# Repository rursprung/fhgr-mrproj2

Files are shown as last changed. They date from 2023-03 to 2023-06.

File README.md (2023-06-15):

# Mobile Robotics Project 2




As part of the [FHGR BSc Mobile Robotics](https://fhgr.ch/mr) an autonomous vehicle with Lidar has been developed
as a group project by [Tim Barmettler](https://github.com/TimBarmettler4), [Joel Flepp](https://github.com/joel5399),
[Yan Gridling](https://github.com/Prince-Sigvald) and [Ralph Ursprung](https://github.com/rursprung) in the 4th
semester.

This repository contains both the code as well as [the PCB schematics](smt_PCB_files/README.md) and
[the 3D printing files](smt_3D_files/README.md) which should allow anyone to build the same robot as an
open-source project.

## What Does "SMT" Mean?

"SMT" stands for "Super Mega Tank". The name was inspired by
the [Super Mega Bot (SMB)](https://github.com/ethz-asl/smb_common) from ETHZ.

## Features

The robot can be operated using the keyboard and driven around. While driving, it creates a map of its environment.
In parallel, a camera is used to scan for a QR code and if this is found, the gun will shoot at the QR code.

### GUI

[rviz](http://wiki.ros.org/rviz) is used to visualise the map, the position of the robot within it as well as the camera
feed (with QR codes being highlighted). Optionally the location of a QR code which has been found can be highlighted as
well.

### Mapping

A 2D map is being created using [SLAM](https://en.wikipedia.org/wiki/Simultaneous_localization_and_mapping) and can be
downloaded using [hector_geotiff](https://wiki.ros.org/hector_geotiff). If it is not downloaded, the data will be lost
once the software is stopped / the robot powered down.
Currently, the robot does not support loading a pre-made map and continue mapping in it.

To save the map to [`smt_slam/maps`](smt_slam/maps) run:

```bash
rostopic pub /syscommand std_msgs/String -1 "data: 'savegeiff'"
```

## Architecture

### Structure

The software is structured along these boundaries:

```mermaid
graph TD
  Teleop -->|"move command<br/>message: <code>geometry_msgs/Twist</code><br/>topic: <code>/cmd_vel</code>"| MC

MC[ Movement Controller ]
MC -->| PWM signal| LM[[ Left Motor ]]
MC -->|PWM signal | RM[[ Right Motor ]]

Camera[[ Camera ]] --> CameraController
CameraController[ Camera Controller ] -->|"image<br/>message: <code>sensor_msgs/Image</code><br/>topic: <code>/camera1/image_raw</code>"| QRCodeFinder
QRCodeFinder[ QR Code Finder ] -->|"QR Code Pose<br/>message: <code>smt_msgs/PoseWithString</code><br/>(= <code>geometry_msgs/Pose</code> + <code>string</code>)<br/>topic: <code>/qr_codes</code>"| QRCodeController

QRCodeController[ QR Code Controller ] -->|"fire command<br/>service: <code>FireAt</code><br/>request:<code>std_msgs/Int32</code> (angle)"| GC
GC[ Gun Controller ] -->| PWM signal| GS
GC -->| Trigger signal | GT
GS[["Gun Servo (height adjust)"]]
GT[[ Gun Trigger ]]

LIDAR[[LIDAR ]] --> rplidar
rplidar[ rplidar_ros ] -->|"point cloud<br/>message: <code>sensor_msgs/LaserScan</code><br/>topic: <code>/scan</code>"| hector_mapping

IMU[["IMU (Bosch BNO055)"]] --> IMUdriver
IMUdriver[ Bosch IMU Driver ] -->|"IMU data<br/>message: <code>sensor_msgs/Imu</code><br/>topic: <code>/imu</code>"| ekf_localization

ekf_localization -->| odom | hector_mapping
ekf_localization -->|odom | tf
hector_mapping["Hector Mapping (SLAM)"] -->| map | tf

hector_mapping -->|"Pose Estimate<br/>message: <code>geometry_msgs/PoseStamped</code><br/>topic: <code>/poseupdate</code>"| ekf_localization

model[ Robot Model ]
model --> robot_state_publisher
model --> joint_state_publisher
robot_state_publisher --> tf
joint_state_publisher --> tf
```

Note that various helper ROS nodes are not shown here. Only the main components are shown.

When running in a simulator ([gazebo](https://gazebosim.org/)) the hardware related controllers will be replaced
with simulator versions thereof, which will then interact with gazebo rather than the real hardware.

Convention used (& invented) for this diagram:

* Hardware is rendered like this:
  ```mermaid
  graph TD
      A[[Some Hardware]]
  ```
* Software (each box is a [ROS node](https://wiki.ros.org/Nodes)) is rendered like this:
  ```mermaid
  graph TD
      A[Some Software]
  ```

### State

```mermaid
stateDiagram-v2
  [*] --> D: turn on
  D --> G: target identified
  G --> D: shot fired

  D: Drive mode (Mapping, QR Code Search)
  G: Gun Mode (shoot at target)
```

## Working With This Repository

As this repository contains code for [ROS](https://ros.org/) (specifically, ROS noetic, the last 1.x release) and uses
the [catkin](https://catkin-tools.readthedocs.io/en/latest/) build tool, you'll need to work in a catkin workspace.

1. Source your ROS setup script (you should preferably add this to your `~/.profile`, esp. if you're working with an
   IDE!)
   ```bash
   source /opt/ros/noetic/setup.bash
   ```
2. Create a new folder for your new catkin workspace (note: you can have multiple catkin workspaces in parallel and also
   source all of their `setup.bash` files at the same time, that works fine):
   ```bash
   cd <wherever you want to have your workspace>/src
   ```
3. Clone this repository into the `src` folder of the workspace:
   ```bash
   git clone --recurse-submodules https://github.com/rursprung/fhgr-mrproj2.git
   ```
   Notes:

* If you cloned it without specifying `src` at the end it'll create a folder named after the repository,
  i.e. `fhgr-mrproj2` - just use `mv fhgr-mrproj2 src` to fix this.
* If you cloned it without specifying `--recurse-submodules` you can still manually init the submodules:
  ```bash
  git submodule init
  git submodule update
  ```

4. Install all required dependencies:
   ```bash
   rosdep install --from-paths . -i

   sudo pip install pynput # see https://github.com/ethz-asl/better_teleop for more details
   ```
5. Build the workspace & source its setup file:
   ```bash
   catkin build
   source devel/setup.bash
   ```
6. Optional: when working with an IDE you should add the sourcing of the `setup.bash` of your workspace also to
   your `~/.profile` (same as the one from ROS) so that it's set for all sessions and your IDE can access it!

### Contributing To The Repository

If you intend to contribute to the repository, please make sure that you're using a fork rather than working directly in
the upstream repository!

Follow the guide above to set up your repository and then:

1. [Create your fork](https://docs.github.com/en/get-started/quickstart/fork-a-repo) on GitHub if you haven't done so
   already
2. Go to your local clone of the repository:
   ```bash
   cd <your workspace>/src
   ```
3. Rename the remote `origin` to `upstream`:
   ```bash
   git remote rename origin upstream
   ```
4. Add your own fork:
   ```bash
   git remote add origin <your fork URL>
   git fetch --all
   ```
5. Follow [the contribution guide](CONTRIBUTING.md) for further details.

### Running The Code

#### Simulation

After building the project you can run the simulated robot using:

```bash
roslaunch smt_launch_gazebo default.launch
```

You can use the arrow keys to navigate in the world.

#### On the Robot

To run the code on the robot you initially need to set up the udev rules for the LIDAR:

```bash
$(rospack find rplidar_ros)/scripts/create_udev_rules.sh
```

This only needs to be done once.

Due to the limited computational power of the Raspberry Pi the compute heavy tasks have been offloaded to a more capable
computer (usually a ROS-specific VM running on your notebook). Accordingly, there are two launch packages, one for the
robot and one for the remote device (which will also start rviz and teleop).
In order for the two to be able to communicate you need to ensure that they can see each other in the network. Note that
for VMs this means that they must have a bridged network adapter instead of NAT so that they have an IP by which they're
reachable from the outside. You'll also need to start `roscore` on one of the two and then set the `ROS_MASTER_URI` on
the second to the first (check the `roscore` output there for the URL with the port number).
Furthermore, it's likely that you need to set the `ROS_IP` and `ROS_HOSTNAME` for things to work properly.

Afterward you can launch the hardware part on the robot:

```bash
roslaunch smt_launch_hardware default.launch
```

And the remote control part on your computer:

```bash
roslaunch smt_launch_remote_control default.launch
```

## License

As this is purely an educational project there's no need for others to include it in their commercial works.
Accordingly, this is licensed under the **GNU General Public License v3.0 or later** (SPDX: `GPL-3.0-or-later`).
See [LICENSE](LICENSE) for the full license text.

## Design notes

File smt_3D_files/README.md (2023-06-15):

# Hardware / 3D Models

Various parts of the robot have been 3D printed. The original files from Fusion as well as the exported
STEP models have been added here so that you can print them yourselves as well.

Additionally, you will need the following hardware components to completely reproduce the project:

* Two DC motors, we used the
  [JGA25-370 Motor](https://media.digikey.com/pdf/Data%20Sheets/Seeed%20Technology/114090046_Web.pdf)
  which we salvaged from two of our previously used
  [YFROBOT 4WD chassis](https://yfrobot.com/products/steering-gear-robot), including the mounting bracket (also salvaged
  from this kit)
* One servo motor
* One toy gun, we used the WLToys V959 Gattling Gun (an add-on for the quad-copter of the same name)

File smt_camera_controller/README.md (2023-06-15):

# SMT Camera Controller

This uses the [raspicam](https://github.com/cedricve/raspicam) library to read the camera images from the hardware and
then publish them on a ROS topic so it can be consumed by other services.

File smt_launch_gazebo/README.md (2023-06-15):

# SMT Simulation (Gazebo) Launch

This launches the simulation of the robot in Gazebo.
Note that the model used in Gazebo is less elaborate than the real hardware, e.g. it is modelled as a wheeled robot
instead of having tracks as this already existed for Gazebo.

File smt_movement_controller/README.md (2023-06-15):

# SMT Movement Controller

This ROS package includes a ROS node designed to operate on a Raspberry Pi 4b, allowing the user to control GPIOs and
adjust velocity accordingly. The [pigpio](https://abyz.me.uk/rpi/pigpio/) library is used for setting the GPIOs.

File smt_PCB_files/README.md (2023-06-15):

# PCB Schematics

The schematics have been created using the [EasyEDA editor](https://easyeda.com/editor), to load them you can open the
document via: Top menu - File - Open - EasyEDA... , and select the json file.
Once you open it in the editor you can save it into a project.

Note that the schematics as provided here still has a bug and required us to solder on a few wires! You should fix this
before ordering a new PCB with these schematics!

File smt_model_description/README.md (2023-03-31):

# SMT Model

## Creating the Model

The creation of this model was achieved using the Python script [fusion2urdf](https://github.com/syuntoku14/fusion2urdf)
developed by [syuntoku14](https://github.com/syuntoku14)

To generate a model of your vehicle, start by designing it in Fusion360 and adding the necessary joints. Then, execute
the Python script, and it will generate a complete package containing all the required files to launch your vehicle in
Gazebo.

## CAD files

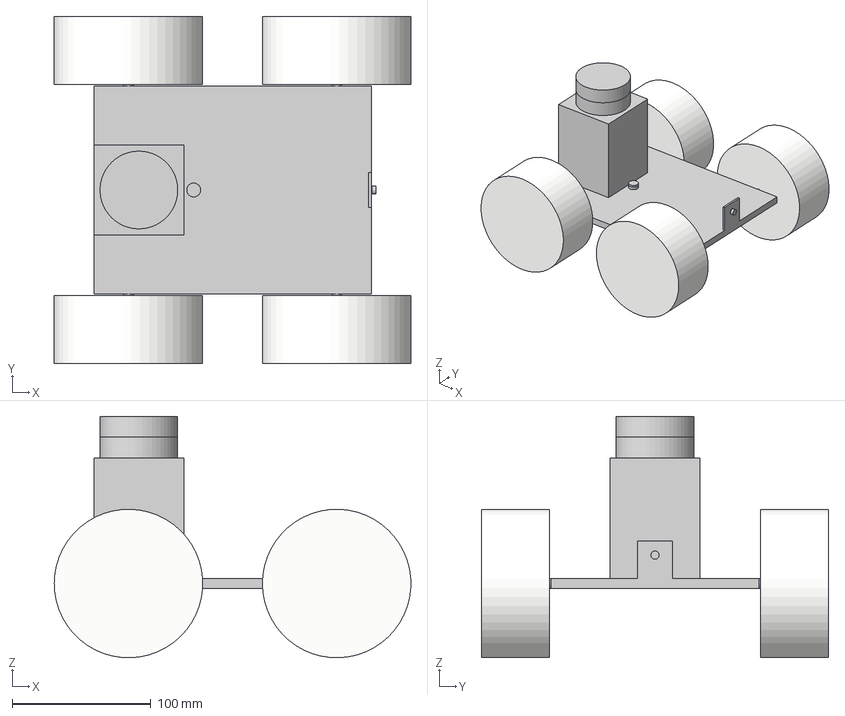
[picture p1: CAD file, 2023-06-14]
smt_3D_files/STEP-files/smt_model_gazebo.step
256.9 x 250.0 x 174.0 mm
base_link
lidar
wheel_right_back
wheel_right_front
wheel_left_back
wheel_left_front
cam
IMU

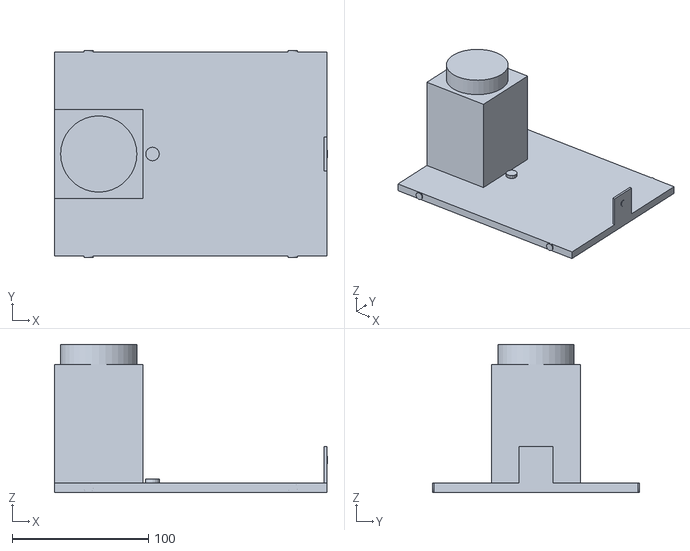
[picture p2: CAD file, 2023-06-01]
smt_model_description/meshes/base_link.stl
200.5 x 152.0 x 109.0

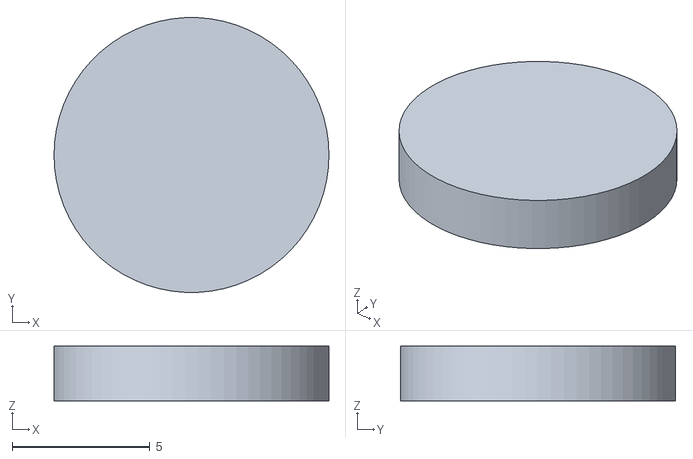
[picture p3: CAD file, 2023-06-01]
smt_model_description/meshes/IMU_1.stl
10.0 x 9.99 x 2.00

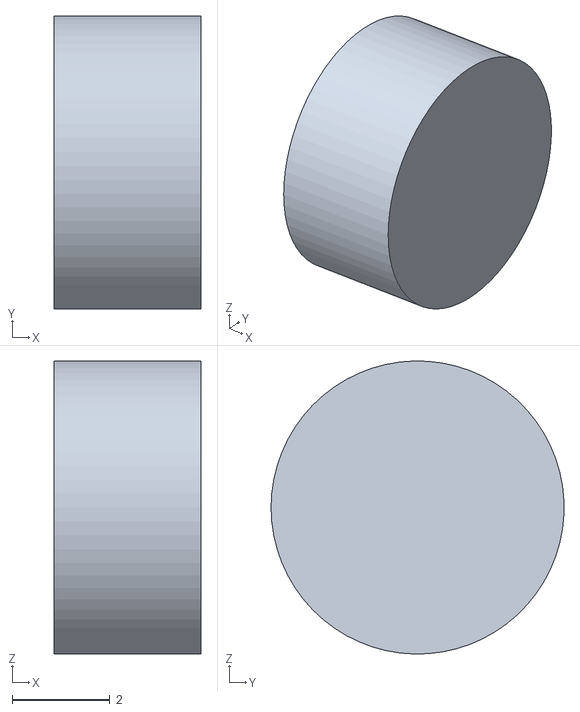
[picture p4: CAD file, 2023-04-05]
smt_model_description/meshes/cam_1.stl
3.00 x 6.00 x 6.00

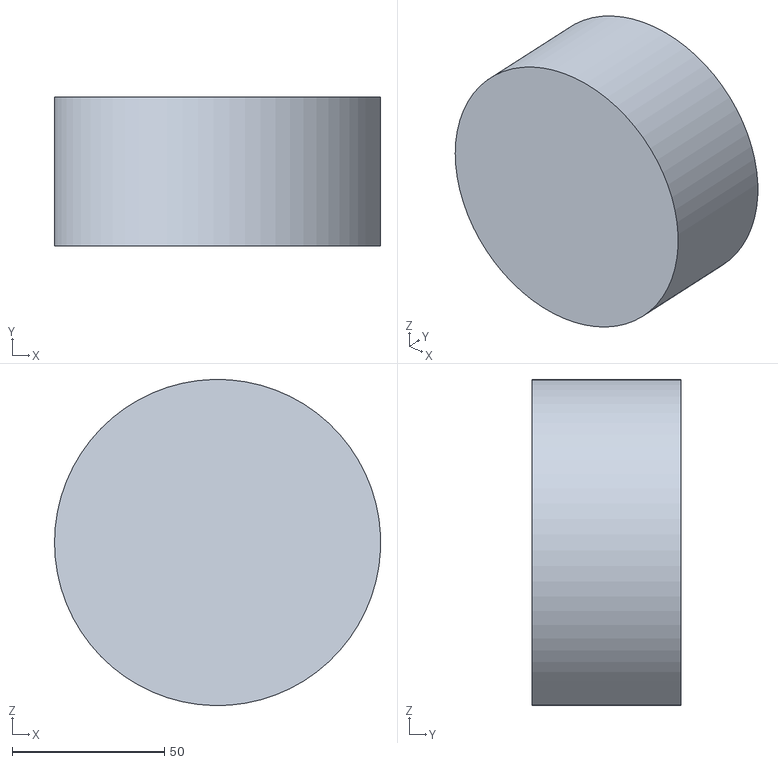
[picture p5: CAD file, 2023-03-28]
smt_model_description/meshes/wheel_left_front_1.stl
106.9 x 49.0 x 107.0

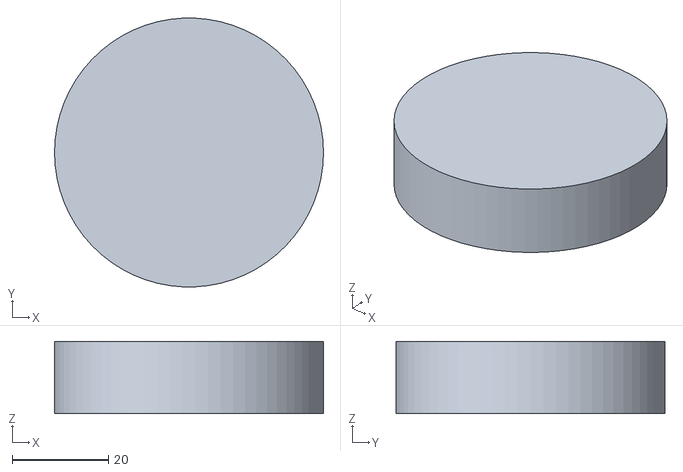
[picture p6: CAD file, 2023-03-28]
smt_model_description/meshes/lidar_1.stl
56.0 x 55.9 x 15.0

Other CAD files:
smt_model_description/meshes/wheel_right_back_1.stl
smt_model_description/meshes/wheel_right_front_1.stl
smt_model_description/meshes/wheel_left_back_1.stl
smt_3D_files/Fusion-files/smt_model_gazebo.f3d

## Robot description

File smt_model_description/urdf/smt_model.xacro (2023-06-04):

<?xml version="1.0" ?>
<robot name="smt_model" xmlns:xacro="http://www.ros.org/wiki/xacro">

  <xacro:include filename="$(find smt_model_description)/urdf/materials.xacro"/>
  <xacro:include filename="$(find smt_model_description)/urdf/smt_model.trans"/>
  <xacro:include filename="$(find smt_model_description)/urdf/smt_model.gazebo"/>
  <link name="base_link">
    <inertial>
      <origin xyz="-0.04442209324525173 -1.4796373389488127e-17 0.08749630601210859" rpy="0 0 0"/>
      <mass value="4.825191431023001"/>
      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
    </inertial>
    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
  </link>

  <link name="wheel_left_front_1">
    <inertial>
      <origin xyz="1.3877787807814457e-17 0.024500000000000008 -1.3877787807814457e-17" rpy="0 0 0"/>
      <mass value="0.46704570436797993"/>
      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
    </inertial>
    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
  </link>

  <link name="wheel_left_back_1">
    <inertial>
      <origin xyz="0.0 0.024500000000000008 6.938893903907228e-18" rpy="0 0 0"/>
      <mass value="0.46704570436797993"/>
      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
    </inertial>
    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
  </link>

  <link name="wheel_right_back_1">
    <inertial>
      <origin xyz="0.0 -0.024500000000000008 0.0" rpy="0 0 0"/>
      <mass value="0.46704570436797993"/>
      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
    </inertial>
    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
  </link>

  <link name="wheel_right_front_1">
    <inertial>
      <origin xyz="1.3877787807814457e-17 -0.024500000000000008 0.0" rpy="0 0 0"/>
      <mass value="0.46704570436797993"/>
      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
    </inertial>
    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
  </link>

  <link name="lidar_1">
    <inertial>
      <origin xyz="0.0 0.0 0.007500000000000007" rpy="0 0 0"/>
      <mass value="0.29001926740879547"/>
      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
    </inertial>
    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
  </link>

  <link name="cam_1">
    <inertial>
      <origin xyz="0.001500000000000043 3.136830235032246e-13 1.3877787807814457e-17" rpy="0 0 0"/>
      <mass value="0.000665860562928387"/>
      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
    </inertial>
    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
  </link>

  <link name="IMU_1">
    <inertial>
      <origin xyz="-5.228407822368264e-13 0.0 0.0010000000000000217" rpy="0 0 0"/>
      <mass value="0.0012330751165340477"/>
      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
    </inertial>
    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
  </link>

  <joint name="Revolute_2" type="continuous">
    <origin xyz="0.075 0.076 0.0535" rpy="0 0 0"/>
    <parent link="base_link"/>
    <child link="wheel_left_front_1"/>
    <axis xyz="0.0 1.0 0.0"/>
  </joint>

  <joint name="Revolute_3" type="continuous">
    <origin xyz="-0.075 0.076 0.0535" rpy="0 0 0"/>
    <parent link="base_link"/>
    <child link="wheel_left_back_1"/>
    <axis xyz="0.0 1.0 0.0"/>
  </joint>

  <joint name="Revolute_4" type="continuous">
    <origin xyz="-0.075 -0.076 0.0535" rpy="0 0 0"/>
    <parent link="base_link"/>
    <child link="wheel_right_back_1"/>
    <axis xyz="0.0 1.0 0.0"/>
  </joint>

  <joint name="Revolute_5" type="continuous">
    <origin xyz="0.075 -0.076 0.0535" rpy="0 0 0"/>
    <parent link="base_link"/>
    <child link="wheel_right_front_1"/>
    <axis xyz="0.0 1.0 0.0"/>
  </joint>

  <joint name="Rigid 6" type="fixed">
    <origin xyz="-0.0675 0.0 0.159" rpy="0 0 0"/>
    <parent link="base_link"/>
    <child link="lidar_1"/>
  </joint>

  <joint name="Rigid 7" type="fixed">
    <origin xyz="0.1005 0.0 0.074" rpy="0 0 0"/>
    <parent link="base_link"/>
    <child link="cam_1"/>
  </joint>

  <joint name="Rigid 8" type="fixed">
    <origin xyz="-0.034 0.0 0.059" rpy="0 0 0"/>
    <parent link="base_link"/>
    <child link="IMU_1"/>
  </joint>

  <joint name="camera_optical_joint" type="fixed">
    <origin xyz="0 0 0" rpy="-1.5708 0 -1.5708"/>
    <parent link="cam_1"/>
    <child link="camera_link_optical"/>
  </joint>

  <link name="camera_link_optical" />

</robot>

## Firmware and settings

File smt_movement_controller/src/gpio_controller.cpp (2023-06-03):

#include <pigpiod_if2.h>
#include "smt_movement_controller/gpio_controller.hpp"
#include "smt_movement_controller/movement_controller.hpp"

enum class Pin {
    PWM_LEFT = 4,      //!< pwm motor Left (Pyhsical 7)
    PWM_RIGHT = 5,     //!< pwm motor right (Physical 29)
    DIR_LEFT_1 = 17,   //!< direction pin left 1 (Physical 11)
    DIR_LEFT_2 = 27,   //!< direction pin left 2 (Physical 13)
    DIR_RIGHT_1 = 6,   //!< direction pin right 1 (Physical 31)
    DIR_RIGHT_2 = 13,  //!< direction pin right 2 (Physical 33)
};

const int PWM_FREQ = 20000;      //!< Hertz
const int PWM_RANGE = 100;       //!< Range for pwm 0% to 100%
const double MAX_SPEED = 0.715;  //!< m/s measured

/**
 * The function maps a value from one range to another range and returns the mapped value, with
 * warnings if the input value is outside the input range.
 *
 * @param value The input value that needs to be mapped to a new range.
 * @param in_min The minimum input value that can be mapped.
 * @param in_max The maximum input value that can be mapped.
 * @param out_min The minimum value of the output range that the input value will be mapped to.
 * @param out_max The maximum output value that the function can return. It is the upper limit of the
 * range of values that the input value will be mapped to.
 *
 * @return a double value that is the result of mapping the input value from the input range (in_min to
 * in_max) to the output range (out_min to out_max). If the input value is outside the input range, the
 * function returns either the out_min or out_max value depending on which boundary is exceeded.
 */
double map(double value, double in_min, double in_max, double out_min, double out_max) {
    if (value < in_min) {
        ROS_WARN("Reached smallest possible value, return value set to out_min Value: %f", out_min);
        return out_min;
    }
    else if (value > in_max) {
        ROS_WARN("Reached highest possible value, return value set to out_max Value: %f", out_max);
        return out_max;
    }
    else {
        return (value - in_min) * (out_max - out_min) / (in_max - in_min) + out_min;
    }
}

namespace smt {

    namespace gpio_controller {

        GpioController::GpioController() {
            this->pi = pigpio_start(NULL, NULL);
            if (this->pi < 0) {
                throw std::runtime_error("error while trying to initialize pigpio!");
                return;
            }

            // PWMs
            set_mode(this->pi, static_cast<uint>(Pin::PWM_LEFT), PI_OUTPUT);
            set_mode(this->pi, static_cast<uint>(Pin::PWM_RIGHT), PI_OUTPUT);

            set_PWM_frequency(this->pi, static_cast<uint>(Pin::PWM_LEFT), PWM_FREQ);
            set_PWM_frequency(this->pi, static_cast<uint>(Pin::PWM_RIGHT), PWM_FREQ);

            set_PWM_range(this->pi, static_cast<uint>(Pin::PWM_LEFT), PWM_RANGE);
            set_PWM_range(this->pi, static_cast<uint>(Pin::PWM_RIGHT), PWM_RANGE);

            // GPIOs
            set_mode(this->pi, static_cast<uint>(Pin::DIR_LEFT_1), PI_OUTPUT);
            set_mode(this->pi, static_cast<uint>(Pin::DIR_LEFT_2), PI_OUTPUT);
            set_mode(this->pi, static_cast<uint>(Pin::DIR_RIGHT_1), PI_OUTPUT);
            set_mode(this->pi, static_cast<uint>(Pin::DIR_RIGHT_2), PI_OUTPUT);

            gpio_write(this->pi, static_cast<uint>(Pin::DIR_LEFT_1), 0);
            gpio_write(this->pi, static_cast<uint>(Pin::DIR_LEFT_2), 0);
            gpio_write(this->pi, static_cast<uint>(Pin::DIR_RIGHT_1), 0);
            gpio_write(this->pi, static_cast<uint>(Pin::DIR_RIGHT_2), 0);
        }

        GpioController::~GpioController() {
            pigpio_stop(this->pi);
        }

        void GpioController::applyMotorSpeed(const double vLeft, const double vRight) const {
            int pwm_val_left = map(abs(vLeft), 0, MAX_SPEED, 0, PWM_RANGE);
            int pwm_val_right = map(abs(vRight), 0, MAX_SPEED, 0, PWM_RANGE);

            gpio_write(this->pi, static_cast<uint>(Pin::DIR_LEFT_1), vLeft <= 0 ? 1 : 0);
            gpio_write(this->pi, static_cast<uint>(Pin::DIR_LEFT_2), vLeft >= 0 ? 1 : 0);

            gpio_write(this->pi, static_cast<uint>(Pin::DIR_RIGHT_1), vRight < 0 ? 0 : 1);
            gpio_write(this->pi, static_cast<uint>(Pin::DIR_RIGHT_2), vRight > 0 ? 0 : 1);

            set_PWM_dutycycle(this->pi, static_cast<uint>(Pin::PWM_LEFT), pwm_val_left);
            set_PWM_dutycycle(this->pi, static_cast<uint>(Pin::PWM_RIGHT), pwm_val_right);
        }


    }  // namespace gpio_controller

}  // namespace smt

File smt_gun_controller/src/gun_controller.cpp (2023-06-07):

#include <ros/ros.h>
#include <std_msgs/Int32.h>
#include <cmath>

#include <pigpiod_if2.h>

#include "smt_gun_controller/gun_controller.hpp"



namespace smt {
    namespace gun_controller {
        enum class Pin {
            GUN_TRIGGER = 18, //!< gun trigger (Pyhsical 12)
            PWM_SERVO = 12,   //!< pwm motor right (Physical 32)
        };

        const int defaultPipeAngle = 0;
        const int minimalPipeAngle = -15;
        const int maximalPipeAngle = 50;
        const uint positivePulseWidthLimitation = 2050;
        const uint negativePulseWidthLimitation = 1250;

        /**
         * This function calculates the pulse width based on the given pipe angle, with limitations on the
         * angle range.
         *
         * @param pipeAngle The angle of a pipe in degrees.
         *
         * @return an integer value which represents the pulseWidth calculated based on the input pipe angle.
         */
        uint getPulseWidthFromPipeAngle(int const pipeAngle) {
            if (pipeAngle < minimalPipeAngle) {
                ROS_WARN("reached minimum angle limitation (%i deg), setting angle to %i deg", minimalPipeAngle, minimalPipeAngle);
                return negativePulseWidthLimitation;
            }

            if (pipeAngle > maximalPipeAngle) {
                ROS_WARN("reached maximum angle limitation (%i deg), setting angle to %i deg", maximalPipeAngle, maximalPipeAngle);
                return positivePulseWidthLimitation;
            }

            return (pipeAngle - minimalPipeAngle) *
                (positivePulseWidthLimitation - negativePulseWidthLimitation) /
                (maximalPipeAngle - minimalPipeAngle) +
                negativePulseWidthLimitation;
        }

        GunController::GunController(ros::NodeHandle& nodeHandle) {
            std::string gunControllerService;

            if (!nodeHandle.getParam("gun_controller_service", gunControllerService)) {
                ROS_ERROR("failed to load the `gun_controller_service` parameter!");
                ros::requestShutdown();
            }

            this->service = nodeHandle.advertiseService(gunControllerService, &GunController::gunCommandCallback, this);
            ROS_INFO_STREAM("starting service " << gunControllerService);

            this->initPi();

            ROS_INFO("init done");
        }

        GunController::~GunController() {
            pigpio_stop(this->pi);
        }

        void GunController::initPi() {
            this->pi = pigpio_start(NULL, NULL);
            if (this->pi < 0) {
                throw std::runtime_error("error while trying to initialize pigpio!");
                return;
            }

            // GPIOs
            set_mode(this->pi, static_cast<uint>(Pin::GUN_TRIGGER), PI_OUTPUT);
            gpio_write(this->pi, static_cast<uint>(Pin::GUN_TRIGGER), 1);

            // PWMs
            set_mode(this->pi, static_cast<uint>(Pin::PWM_SERVO), PI_OUTPUT);
            this->moveGunToAngle(defaultPipeAngle);
        }

        bool GunController::gunCommandCallback(smt_svcs::FireGun::Request& request, smt_svcs::FireGun::Response& response) {
            this->moveGunToAngle(request.angle);

            // use a small delay to make it look smoother
            ros::Duration(0.5).sleep();
            fireShot();
            ros::Duration(0.5).sleep();

            this->moveGunToAngle(defaultPipeAngle);

            response.success = true;
            return true;
        }

        void GunController::fireShot() const {
            gpio_write(this->pi, static_cast<uint>(Pin::GUN_TRIGGER), 0);
            ros::Duration(0.1).sleep();
            gpio_write(this->pi, static_cast<uint>(Pin::GUN_TRIGGER), 1);
        }

        void GunController::moveGunToAngle(int const targetAngle) const {
            auto const targetPulseWidth = getPulseWidthFromPipeAngle(targetAngle);

            set_servo_pulsewidth(this->pi, static_cast<uint>(Pin::PWM_SERVO), targetPulseWidth);
            ros::Duration(0.5).sleep();
        }

    } // namespace movement_controller
} // namespace smt

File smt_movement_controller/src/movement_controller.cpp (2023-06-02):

#include <pigpio.h>
#include <ros/ros.h>

#include "smt_movement_controller/movement_controller.hpp"
#include "smt_movement_controller/gpio_controller.hpp"

namespace smt {
    namespace movement_controller {
        MovementController::MovementController(ros::NodeHandle& nodeHandle) {
            std::string velTopic;
            int subscriberQueueSize;
            if (!nodeHandle.getParam("cmd_vel_topic/topic", velTopic)) {
                ROS_ERROR("failed to load the `cmd_vel_topic/topic` parameter!");
                ros::requestShutdown();
            }

            if (!nodeHandle.getParam("cmd_vel_topic/queue_size", subscriberQueueSize)) {
                ROS_ERROR("failed to load the `cmd_vel_topic/queue_size` parameter!");
                ros::requestShutdown();
            }

            velSubscriber = nodeHandle.subscribe(velTopic, subscriberQueueSize, &MovementController::velocityCommandCallback, this);
            ROS_INFO("starting subscriber for %s with queue size %i", velTopic.c_str(), subscriberQueueSize);

            ROS_INFO("init done");
        }

        void MovementController::velocityCommandCallback(const geometry_msgs::Twist::ConstPtr& velocity) const {
            std::pair<double, double> leftAndRightSpeed = mapRobotVelocityToMotorSpeed(velocity->linear.x, velocity->angular.z);
            this->gpioController.applyMotorSpeed(leftAndRightSpeed.first, leftAndRightSpeed.second);
        }

        std::pair<double, double> MovementController::mapRobotVelocityToMotorSpeed(const double& linear_speed, const double& angular_speed) const {
            double wheelSeperation = 0.201;  // Wheelseperation in m
            double vel_mot_left = linear_speed - (angular_speed * wheelSeperation) / 2;
            double vel_mot_right = linear_speed + (angular_speed * wheelSeperation) / 2;
            return { vel_mot_left, vel_mot_right };
        }

    }  // namespace movement_controller
}  // namespace smt

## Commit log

2023-03-12 add GitHub code owner configuration
    this ensures that the right people are added as reviewers to pull
    requests modifying files in their area.
    as we don't have any specific content yet all team members are just
    added as default reeviewers for everything. when adding more content we
    can see if it makes sense to specify specific people for certain areas.
    see the [documentation][gh-docs] for further details on how this file
    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
2023-03-26 define APIs
    this adds a first draft for how the APIs should look like. most
    communication will happen with ROS messages, however triggering the gun
    will be a service call (because it has to happen exactly then).
    the speed sensors on the tracks have been removed because they were not
    accurate enough, accordingly they have also been removed from the
    diagram.
    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
2023-03-28 Add a new model for the smt in gazebo
    This commit adds a new Gazebo model for the SMT robot that allows for testing of its features in simulation without requiring a physical robot. To reduce the computational load of the simulation, the model replaces the two tracks of the robot with two wheels on each side. The exact torque and traction of the wheels will need to be measured on the physical robot and adjusted in the model if necessary.
    [base_link.stl, lidar_1.stl, materials.xacro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]
2023-03-30 fix line-endings of all files in the repository
    the files under `smt_model_description` were formatted with
    Windows-style line-endings (CRLF) instead of Unix-style line-endings
    (LF).
    the fix has been done in an automated way using this command:
    ```bash
    git add --renormalize .
    ```
    this can also be found in the [`.gitattributes` documentation].
    [`.gitattributes` documentation]: https://www.git-scm.com/docs/gitattributes
    [materials.xacro, smt_model.xacro]
2023-03-30 run auto-format on all files
    this fixes the indentation of the files. the IDE is configured by the
    previously added `.editorconfig`, i.e. this should now always be the
    same for everyone.
    [materials.xacro, smt_model.xacro]
2023-04-04 Add Camera to model and add new world
    [base_link.stl, cam_1.stl, smt_model.xacro]
2023-04-04 Add the 3D-files for the smt
    [smt_model_gazebo.step]
2023-04-05 Added Fusion 360 files
    [smt_model_gazebo.f3d, smt_model_gazebo.step]
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2023-04-12 Add new optical link for correct orientation
    [smt_model.xacro]
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2023-04-27 add dependency to `pigpio` library in CMake build
    use CMake's [`ExternalProject`] functionality to pull in the [`pigpio`]
    library.
    we explicitly check out the latest release tag (instead of just the
    default branch) to ensure that we always have the same version.
    the installation directory is explicitly specified as otherwise it tries
    to install the library globally, which would require root access. as we
    only need it for our build we don't want to interfer with the rest of
    the system and don't need root.
    in the best case this would've been mostly provided by the library
    directly, but so far this isn't the case. two issues,
    joan2937/pigpio#572 and joan2937/pigpio#573 have been raised by me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
2023-04-27 Add smt_movement_controller
    This consumens the velocity commands and trigers the correct pins using pigpio
2023-05-01 add `better_teleop` as git submodule
    this adds the [`better_teleop`] package which provides keyboard
    operation for the robot. it currently has to be added as a git submodule
    as it is not (yet) published in such a way that it could be installed
    using `rosdep install` (this might eventually come, but probably too
    late for us; i've raised ethz-asl/better_teleop#3 for this).
    in order to use this properly as a quick-win we need to manually run
    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
2023-05-14 add `smt_launch_hardware`
    with this running `roslaunch smt_launch_hardware default.launch` will
    launch all required nodes to run the logic on the actual hardware (a
    Raspberry Pi 4).
    note that this does not launch rviz, teleop or anything else as it makes
    no sense to run this on the robot. instead, you can set your
    `ROS_MASTER_URI` on your own device to point at the robot (see the
    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
2023-05-17 resolved bugs of last commit
    [movement_controller.cpp]
2023-05-24 add `rplidar_ros` for HW launch
    the [`rplidar_ros`] package is used to read the data from the physical
    LIDAR and create ROS messages out of it. this package is provided by the
    manufacturer of the LIDAR.
    note that after this commit you need to run
    rosdep install --from-paths . -i
    again. and on RPi used on the robot you once need to run the script to
    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
2023-05-24 add map to RViz config
    note: the RViz config is currently in the `smt_model_description`
    package which isn't correct (it e.g. shouldn't know about the map), i'll
    fix this in a follow-up commit.
2023-05-26 add IMU to gazebo simulation
    [IMU_1.stl, base_link.stl, smt_model.xacro]
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2023-05-31 add ekf localization for odom->base_link transform
    this adds a `ekf_localization_node` (from the [`robot_localization`]
    package) so that we can have an odometry frame.
    since we don't have a wheeled robot it's hard to have wheel odometry
    (though we could probably do something with our tracks as well, but this
    is less common).
    instead, we use the data from our newly added IMU and also fuse it with
    the pose estimate created by our mapping tool (see `poseupdate` in the
    [`hector_mapping`] documentation).
    at the moment this seems to have quite a bit of drift when creating a
    map, some fine-tuning might be possible.
    [`robot_localization`]: https://wiki.ros.org/robot_localization
    [`hector_mapping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
2023-06-01 correlate position of IMU according to real IMU
    [IMU_1.stl, base_link.stl, smt_model.xacro]
2023-06-01 HW launch: use `lidar_1` as `frame_id`
    by default the `rplidar.launch` sets the `frame_id` to `laser`, which is
    different from what we've set in our model and what we use in our
    configuration. accordingly, the mapping algorithm so far failed to
    properly handle the laser scan messages.
    as `rplidar.launch` doesn't expose this as an argument i instead just
    copied over the whole node launch code and adjusted this one line.
2023-06-01 also publish model transform for real robot
    so far this was only done in the gazebo case, but in reality we always
    need it.
2023-06-01 smt_model_description: add dependency to urdf
    this should've always been there but was somehow missed. no functional
    impact as the dependencies seem to be installed already anyway.
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2023-06-01 IMU: remove gravity only in simulation
    our BNO055 in reality already removes the gravity, so we mustn't do this
    again here.
2023-06-01 rewrite `pigpio` code to `pigpiod_if2`
    we currently start a `pigpiod` as part of our own process. this has
    several drawbacks:
    * "there can be only one!": we cannot have two packages interacting with
    the GPIO pins separately (e.g. one the movement & gun controllers)
    * there's already a `pigpiod` running on the default port 8888, so we
    currently have to manually set ours to 8889
    * if our application doesn't terminate properly we have to kill it
    manually to be able to start it again
    * we need to launch our node which uses `pigpio` with `sudo` for it to
    work
    instead of using our current approach with [the C interface][pigpio-cif]
    we can use [pigpiod_if2]. this is an API which connects t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
    [gpio_controller.cpp, movement_controller.cpp]
2023-06-02 movement controller: use default SIGINT handler
    this was a leftover from when we tried to have a custom SIGINT handler.
    because this is still here but our custom SIGINT handler isn't we
    currently don't have any SIGINT handler and the application isn't being
    terminated properly.
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2023-06-03 edit position of imu rigid
    [smt_model.xacro]
2023-06-03 implement gun controller
    this adds a basic gun controller which will run on the physical hardware
    and allow moving the gun up/down and firing it.
    this has been ported from the original PR from Joel to the new approach
    based on `pigpiod_if2` and some further cleanups applied.
    this currently uses a ROS topic, however this would probably be more
    suited to a ROS service based on how this is supposed to be used.
    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
2023-06-03 add & launch `bosch_imu_driver` on hardware
    the simulated IMU has already been added, but we haven't added the
    hardware driver for our [Bosch BNO055] yet.
    since the driver isn't released through the ROS infrastructure we
    instead have to pull in the git dependency directly.
    [Bosch BNO055]: https://www.bosch-sensortec.com/products/smart-sensors/bno055/
2023-06-04 gazebo: set `gaussianNoise` for IMU
    the simulated IMU sends relatively bad data (e.g. the z acceleration
    isn't fixed at 9.81 but fluctuates wildely around that number). however,
    so far the covariance in the IMU data was always set to 0.0 which meant
    that the `ekf_localization_node` thought that the data was perfect and
    used it as the primary source, thus leading to wrong position estimates
    for the `odom` frame.
    by setting the `gaussianNoise` it now sets a covariance and the
    localization algorithm gives the IMU data slightly less weight.
    the number 0.5 was arrived at experimentally, it seems to give a good
    result: this allows mapping the whole map in gazebo without any
    noticeable drift.
2023-06-04 flipped camera image
2023-06-06 add framework for QR code detection
    this adds the necessary ROS infrastructure to detect QR codes, calculate
    their position and publish this information so that it can be consumed
    by another node (which will be added afterwards and which will publish
    commands to the gun to fire it at the target, possibly also at the robot
    to move it into place).
    the `smt_qr_msgs` package contains the message structure(s) used to
    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
2023-06-07 implement QR-code pose calculation
    note that the orientation is currently left empty (or rather: set to the
    same as the camera, as if we'd always be facing exactly the QR code)
    which is of course wrong.
    this might be added at some later point, but it's not really needed
    right now.
2023-06-14 updated 3D-Files of the smt
    [smt_model_gazebo.f3d, smt_model_gazebo.step]
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

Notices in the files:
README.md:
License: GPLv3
